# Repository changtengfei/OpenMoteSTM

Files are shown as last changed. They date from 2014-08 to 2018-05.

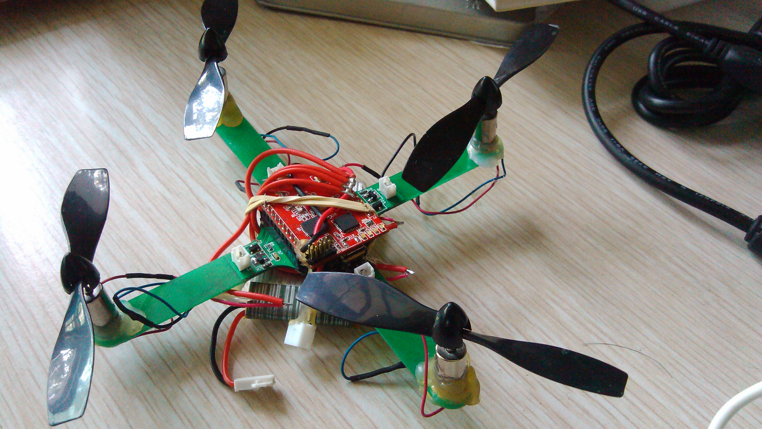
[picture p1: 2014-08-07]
openquadcopter.jpg

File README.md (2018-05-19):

View this project on [CADLAB.io](https://cadlab.io/project/1063). 

OpenSource Hardware of OpenMoteSTM
====================================================

Hello, here is the source of OpenMoteSTM board, including device library, schematic and PCB. All of those are designed by eagle. We also provide a 3d model for openmotestm using sketchUp!!! You can open the openmotestm.skp file with sketchUp to see what openmotestm looks like. Part of package/device/model came from the library of eagle and sparkfun. 

Using OpenMoteSTM with OpenWSN
====================================================

Hardware & Tools
----------------------------------------------------

* OpenMoteSTM Motes         Please Contact: tengfei.chang@gmail.com
* Micro-B USB Cables        You can buy them online anywhere, or maybe you already have one :)
* Jlink Debugger            https://www.segger.com/jlink-debug-probes.html
* Jlink adapter             https://www.segger.com/jlink-adapters-9pin-cortexm.html

Software Installation
----------------------------------------------------

* IAR Embedded Workbench for ARM : Version 6.60     http://www.iar.com
* python 2.7:               http://python.org/download/
* PySerial 2.6:             http://pyserial.sourceforge.net/
* PyDispatcher 2.0.3:       http://pydispatcher.sourceforge.net/
* PyWin32:                  https://sourceforge.net/projects/pywin32/files/pywin32/
* SCons:                    http://scons.org/download.php
* Tap for Windows:          http://openvpn.net/index.php/download/community-downloads.html
* Silicon Labs CP2102:      http://www.silabs.com/support/pages/document-library.aspx?p=Interface&f=USB%20Bridges&pn=CP2102

Installation of Tap
----------------------------------------------------
1. install tun
2. configure tun
    * Go: "Start"->"Programs"->Tap For Windows->utilities->"Add a new TAP virtual ethernet adapter" 
    * Open Network Adapter，Looking for "Local Area Connection" adapter which is created by Tap windows
    * Rename it by "OpenWSN"
    * Enter following code in a windows command prompt， setting IP：
    
            netsh interface ipv4 add address name=OpenWSN address=10.2.0.1 mask=255.255.0.0
            netsh interface ipv6 add address interface=OpenWSN address=bbbb::1/64   
    
    * Enable Routing ("IEEE802.3" is the network interface you are using to connect to internet)

            netsh interface ipv4 set interface interface=IEEE802.3 forwarding=enabled
            netsh interface ipv4 set interface interface=OpenWSN forwarding=enabled

            netsh interface ipv6 set interface interface=IEEE802.3 forwarding=enabled
            netsh interface ipv6 set interface interface=OpenWSN forwarding=enabled
    
    * Add path to routing table

            netsh interface ipv6 delete route bbbb::/64 OpenWSN
            netsh interface ipv6 add    route bbbb::/64 OpenWSN fe80::8

Source Code
-----------------------------------------------------
* openwsn-sw:               https://codeload.github.com/openwsn-berkeley/openwsn-sw/zip/REL-1.8.0
* openwsn-fw:               https://codeload.github.com/openwsn-berkeley/openwsn-fw/zip/REL-1.8.0
* coap:                     https://codeload.github.com/openwsn-berkeley/coap/zip/develop

-All extracted folders need to be place at same level-

Downloading led_blink Program
-----------------------------------------------------
1. Open "IAR for ARM"
2. GO: File->Open->Workspace
3. choosing "openmotestm.eww"
    * the file is at : openwsn-fw-REL-1.8.0\projects\openmotestm directory
4. All the projects will shown on the Workspace(left of the GUI)，right click to select "01bsp_leds-Debug" project, then choose "Set as Active" in the prompt menu.    
5. Downloading and Debugging by left clicking the "Green Triangle Button",
    * tips: "Ctrl + D" is the short-cut of this functions
6. After downloading，IAR will stop at debugging mode. Press F5 to start the program. You will see the LEDs will blink by sequence

Using OpenWSN Program
-----------------------------------------------------
1. Downloading "03oos_openwsn-Debug" program by the procedures above
2. Connect OpenMoteSTM to PC by USB Cabel，PC will install the Silicon driver for OpenMoteSTM
3. Open a windows prompt, and enter the following code to start openvisualizer
        cd "Your\openwsn-sw_REL-1.8.0\Directory"\software\openvisualizer\
        scons runweb
3. Open your favourite brower and type in "localhost:8080" or "127.0.0.1:8080", You will see the openwsn openvisualizer page.
4. click "toggle" button to set the mote as DAGROOT. If everything goes well, you will find the blue LED light and the green one blinks. To see what's going behind them, please visit: http://openwsn.org

Contact & Help
-----------------------------------------------------
If you have any questions, please don't hesitate to contact tengfei.chang@gmail.com

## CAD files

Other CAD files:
3dmodel/USBDongle.skp
3dmodel/openmotestm-kit.skp
3dmodel/openmotestm.skp
3dmodel/openquadcopter.skp
3dmodel/testbed-plank.skp

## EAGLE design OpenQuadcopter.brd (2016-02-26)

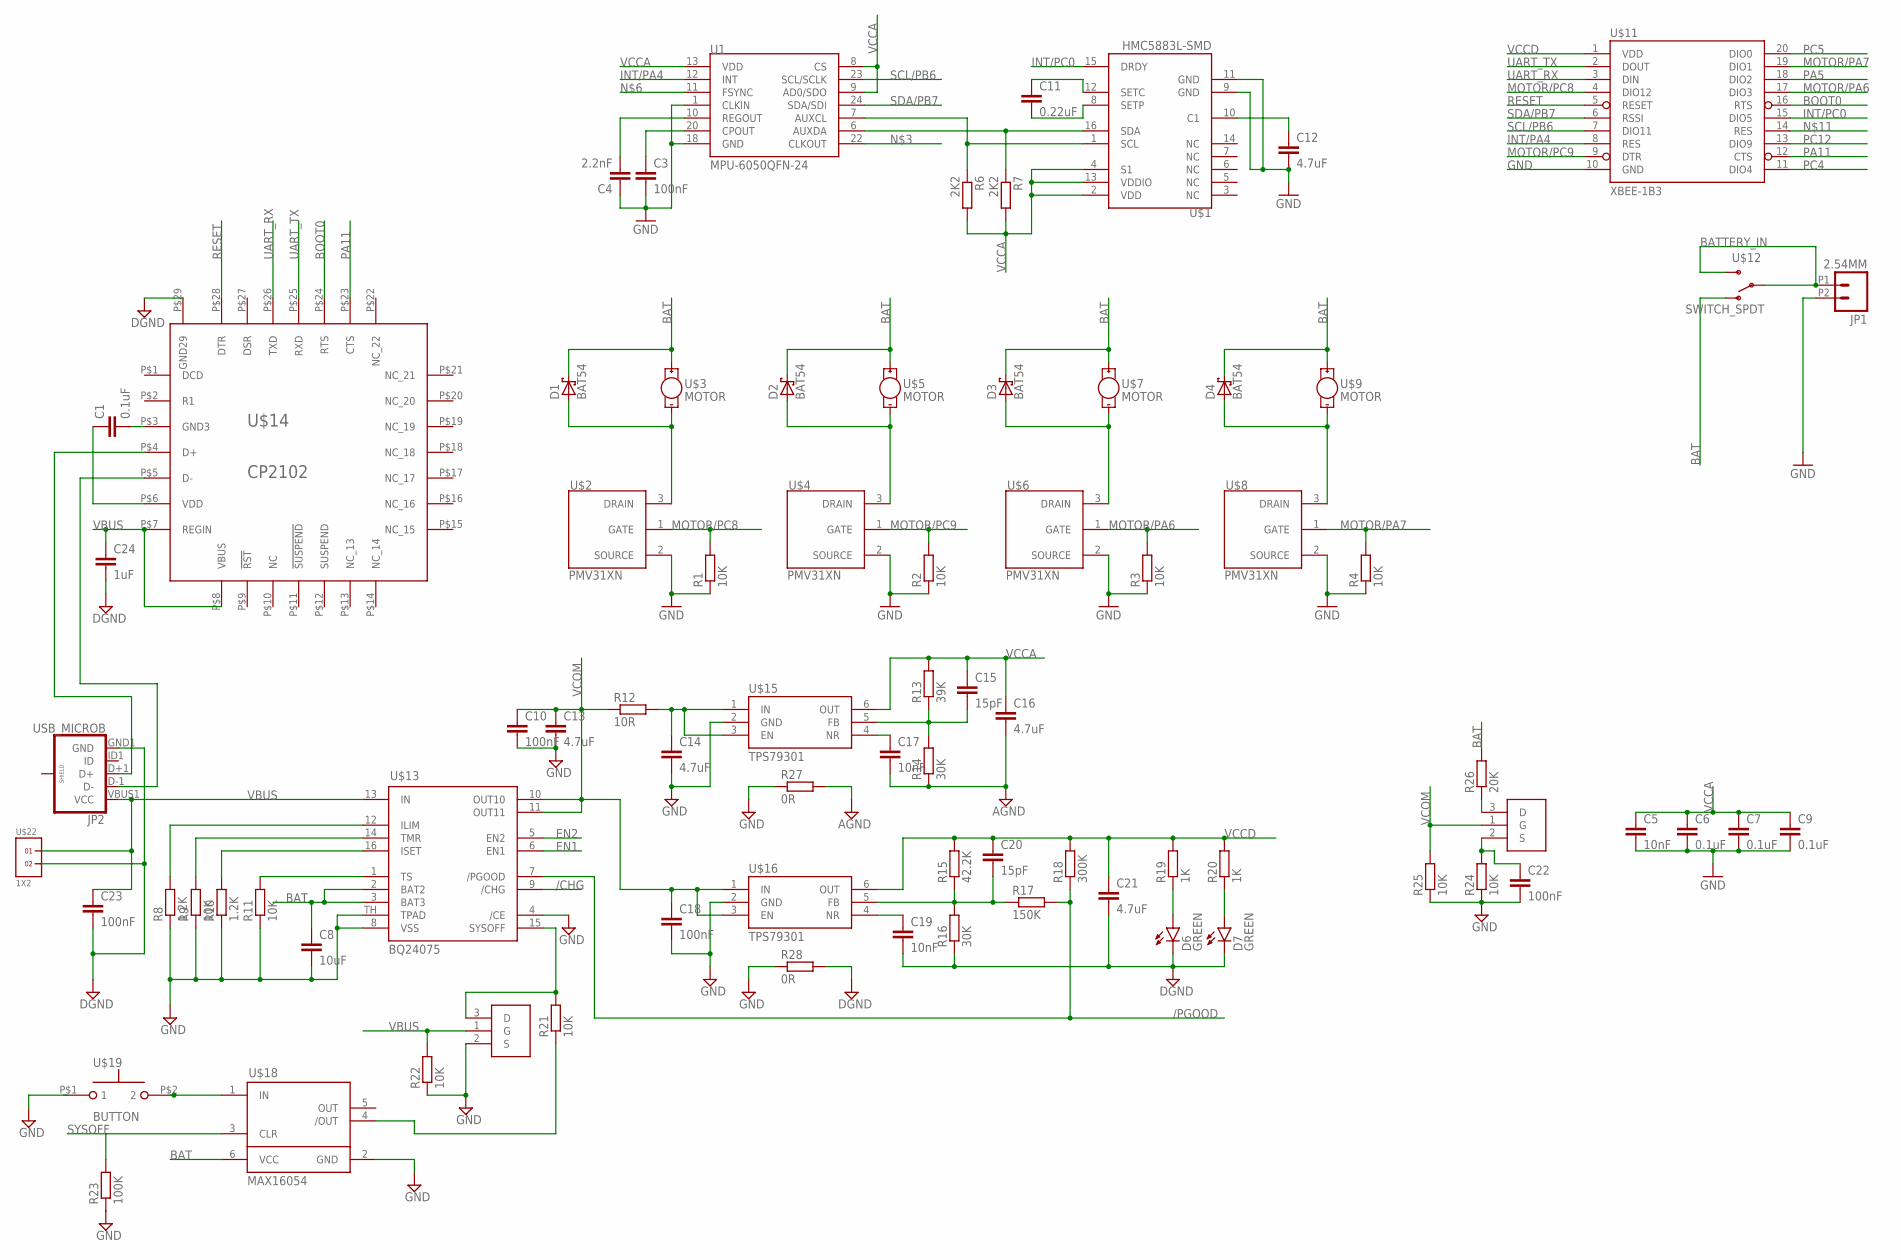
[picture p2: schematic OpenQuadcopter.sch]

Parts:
C1, C6, C7, C9: 0.1uF; C0402
C3, C10, C18, C22, C23: 100nF; C0402
C4: 2.2nF; C0402
C5, C17, C19: 10nF; C0402
C8: 10uF; C0603
C11: 0.22uF; C0402
C12, C13, C14, C16, C21: 4.7uF; C0603
C15, C20: 15pF; C0402
C24: 1uF; C0603
D1, D2, D3, D4: BAT54; SOT23
D6, D7: GREEN; LED-0603
JP1: 2.54MM; 1X02_2.54_SCREWTERM
JP2: USB_MICROB; USB-B-MICRO-SMD_V03
R1, R2, R3, R4, R9, R11, R21, R22, R24, R25: 10K; R0402
R6, R7: 2K2; R0402
R8, R10: 1.2K; R0402
R12: 10R; R0402
R13: 39K; R0402
R14, R16: 30K; R0402
R15: 42.2K; R0402
R17: 150K; R0402
R18: 300K; R0402
R19, R20: 1K; R0402
R23: 100K; R0402
R26: 20K; R0402
R27, R28: 0R; R0402
U1: MPU-6050QFN-24; QFN-24-TESTING
U$1: HMC5883L-SMD; 16LPCC
U$2, U$4, U$6, U$8: PMV31XN; SOT23-W
U$3, U$5, U$7, U$9: MOTOR; VIBE-MOTOR-10MM
U$11: XBEE-1B3; XBEE-SMD
U$12: SWITCH_SPDT; KPS-1290
U$13: BQ24075; QFN16
U$14: CP2102; QFN28-5X5
U$15, U$16: TPS79301; SOT23-6
U$17, U$20: 2N7002; SOT23-3
U$18: MAX16054; SOT23-6
U$19: BUTTON
U$22: 1X2

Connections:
/CHG: U$13.9 (/CHG)
/PGOOD: R17.2, R18.1, U$13.7 (/PGOOD)
AGND: C16.2, C17.2, R14.1, R27.2
BAT: C8.1, D1.3 (C), D2.3 (C), D3.3 (C), D4.3 (C), R26.2, U$3.+, U$5.+, U$7.+, U$9.+, U$12.O, U$13.2 (BAT2), U$13.3 (BAT3), U$18.6 (VCC)
BATTERY_IN: JP1.P1 (1), U$12.P, U$12.S
BOOT0: U$11.16 (RTS), U$14.P$24 (RTS)
DGND: C19.2, C21.2, C23.2, C24.2, D6.C, D7.C, JP2.GND1 (GND), R16.1, R28.2, U$14.P$29 (GND29), U$22.2
EN1: U$13.6 (EN1)
EN2: U$13.5 (EN2)
GND: C3.2, C4.1, C5.2, C6.2, C7.2, C8.2, C9.2, C10.2, C12.2, C13.2, C14.2, C18.2, C22.2, JP1.P2 (2), R1.1, R2.1, R3.1, R4.1, R8.1, R9.1, R10.1, R11.1, R22.1, R23.1, R24.1, R25.1, R27.1, R28.1, U1.1 (CLKIN), U1.18 (GND), U$1.9 (GND), U$1.11 (GND), U$2.2 (SOURCE), U$4.2 (SOURCE), U$6.2 (SOURCE), U$8.2 (SOURCE), U$11.10 (GND), U$13.4 (/CE), U$13.8 (VSS), U$13.TH (TPAD), U$15.2 (GND), U$16.2 (GND), U$17.2 (S), U$18.2 (GND)
INT/PA4: U1.12 (INT), U$11.8 (RES)
INT/PC0: U$1.15 (DRDY), U$11.15 (DIO5)
MOTOR/PA6: R3.2, U$6.1 (GATE), U$11.17 (DIO3)
MOTOR/PA7: R4.2, U$8.1 (GATE), U$11.19 (DIO1)
MOTOR/PC8: R1.2, U$2.1 (GATE), U$11.4 (DIO12)
MOTOR/PC9: R2.2, U$4.1 (GATE), U$11.9 (DTR)
unnamed: D2.1 (A), U$4.3 (DRAIN), U$5.-
unnamed: D1.1 (A), U$2.3 (DRAIN), U$3.-
unnamed: R6.1, U1.7 (AUXCL), U$1.1 (SCL)
unnamed: D3.1 (A), U$6.3 (DRAIN), U$7.-
unnamed: D4.1 (A), U$8.3 (DRAIN), U$9.-
unnamed: R7.1, U1.6 (AUXDA), U$1.16 (SDA)
unnamed: C4.2, U1.10 (REGOUT)
unnamed: C1.2, U$14.P$3 (GND3)
unnamed: C3.1, U1.20 (CPOUT)
unnamed: C11.1, U$1.12 (SETC)
unnamed: C11.2, U$1.8 (SETP)
unnamed: R21.1, U$18.4 (/OUT)
unnamed: C12.1, U$1.10 (C1)
unnamed: C1.1, U$14.P$6 (VDD)
unnamed: R8.2, U$13.12 (ILIM)
unnamed: R9.2, U$13.14 (TMR)
unnamed: R10.2, U$13.16 (ISET)
unnamed: R11.2, U$13.1 (TS)
unnamed: R21.2, U$13.15 (SYSOFF), U$17.3 (D)
unnamed: C14.1, R12.2, U$15.1 (IN), U$15.3 (EN)
unnamed: U$18.1 (IN), U$19.P$2 (2)
unnamed: C15.2, R13.1, R14.2, U$15.5 (FB)
unnamed: C17.1, U$15.4 (NR)
unnamed: C19.1, U$16.4 (NR)
unnamed: C20.2, R15.1, R16.2, R17.1, U$16.5 (FB)
unnamed: C22.1, R24.2, U$20.2 (S)
unnamed: D6.A, R19.1
unnamed: D7.A, R20.1
unnamed: R26.1, U$20.3 (D)
unnamed: JP2.D+1 (D+), U$14.P$4 (D+)
unnamed: JP2.D-1 (D-), U$14.P$5 (D-)
PA5: U$11.18 (DIO2)
PA11: U$11.12 (CTS), U$14.P$23 (CTS)
PC4: U$11.11 (DIO4)
PC5: U$11.20 (DIO0)
PC12: U$11.13 (DIO9)
RESET: U$11.5 (RESET), U$14.P$28 (DTR)
SCL/PB6: U1.23 (SCL/SCLK), U$11.7 (DIO11)
SDA/PB7: U1.24 (SDA/SDI), U$11.6 (RSSI)
SYSOFF: R23.2, U$18.3 (CLR)
UART_RX: U$11.3 (DIN), U$14.P$26 (TXD)
UART_TX: U$11.2 (DOUT), U$14.P$25 (RXD)
VBUS: C23.1, C24.1, JP2.VBUS1 (VCC), R22.2, U$13.13 (IN), U$14.P$7 (REGIN), U$14.P$8 (VBUS), U$17.1 (G), U$22.1
VCCA: C5.1, C6.1, C7.1, C9.1, C15.1, C16.1, R6.2, R7.2, R13.2, U1.8 (CS), U1.9 (AD0/SDO), U1.13 (VDD), U$1.2 (VDD), U$1.4 (S1), U$1.13 (VDDIO), U$15.6 (OUT)
VCCD: C20.1, C21.1, R15.2, R18.2, R19.2, R20.2, U$11.1 (VDD), U$16.6 (OUT)
VCOM: C10.1, C13.1, C18.1, R12.1, R25.2, U$13.10 (OUT10), U$13.11 (OUT11), U$16.1 (IN), U$16.3 (EN), U$20.1 (G)

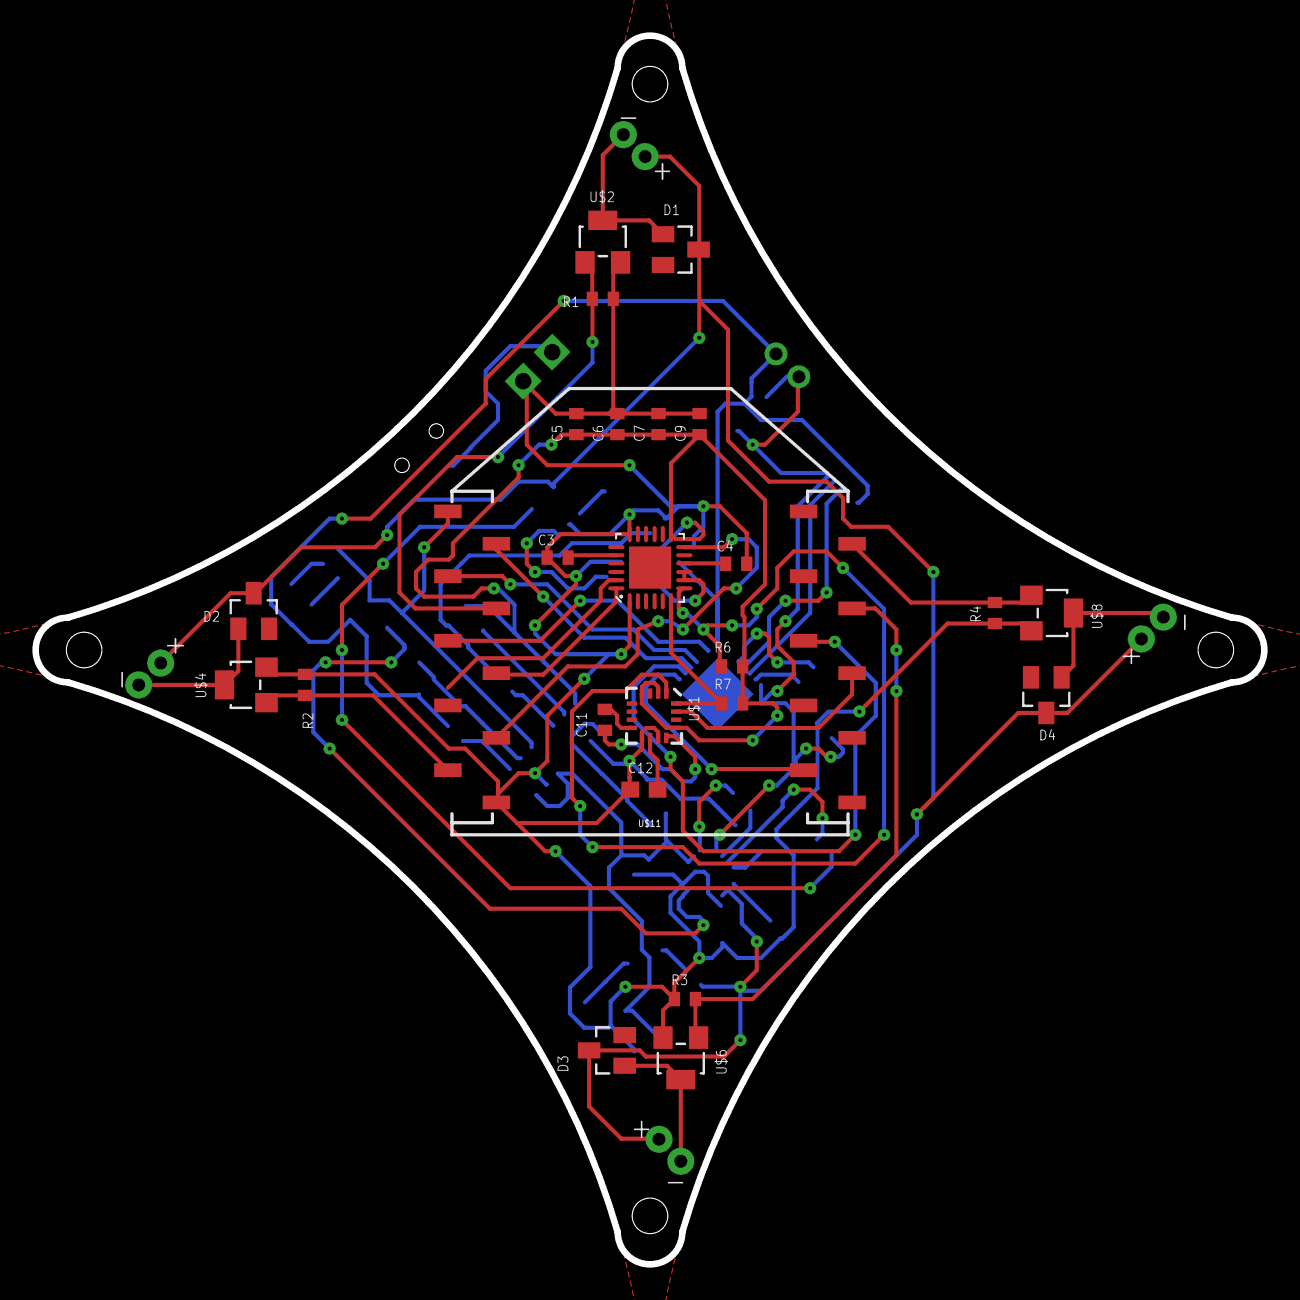
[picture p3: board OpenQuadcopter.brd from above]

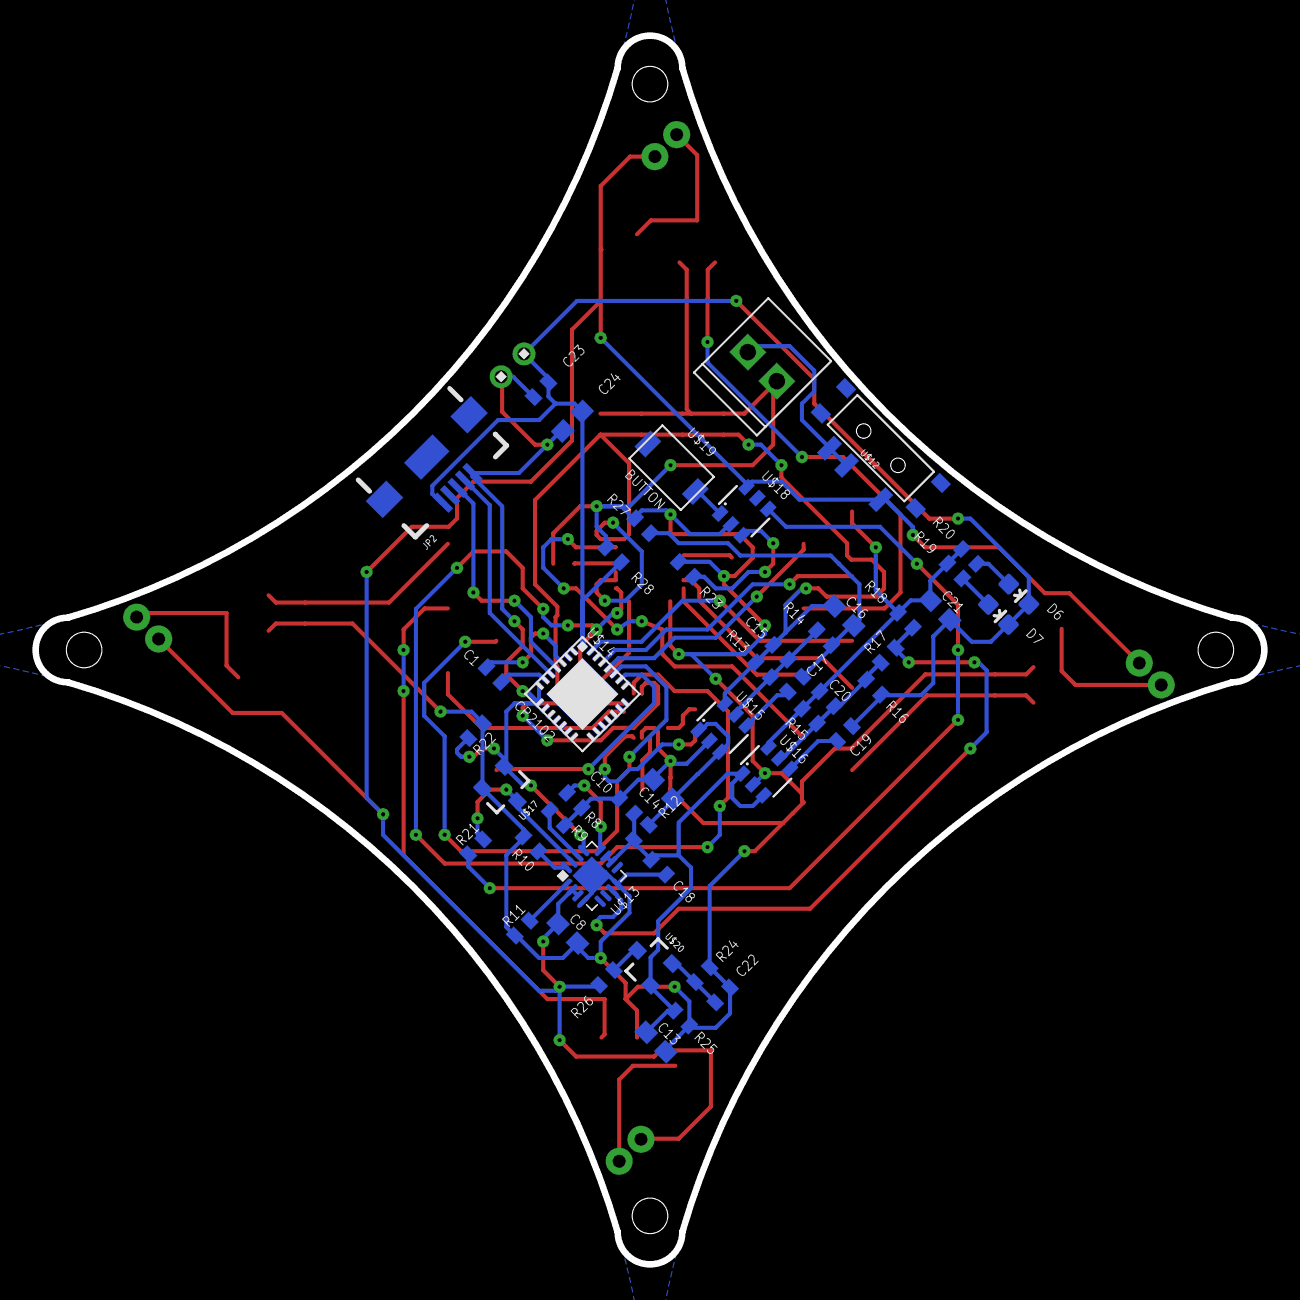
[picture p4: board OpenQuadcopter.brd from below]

Board: 2 copper layers, 76.0 x 76.0 mm, 79 parts (50 on the bottom side), 55 nets.

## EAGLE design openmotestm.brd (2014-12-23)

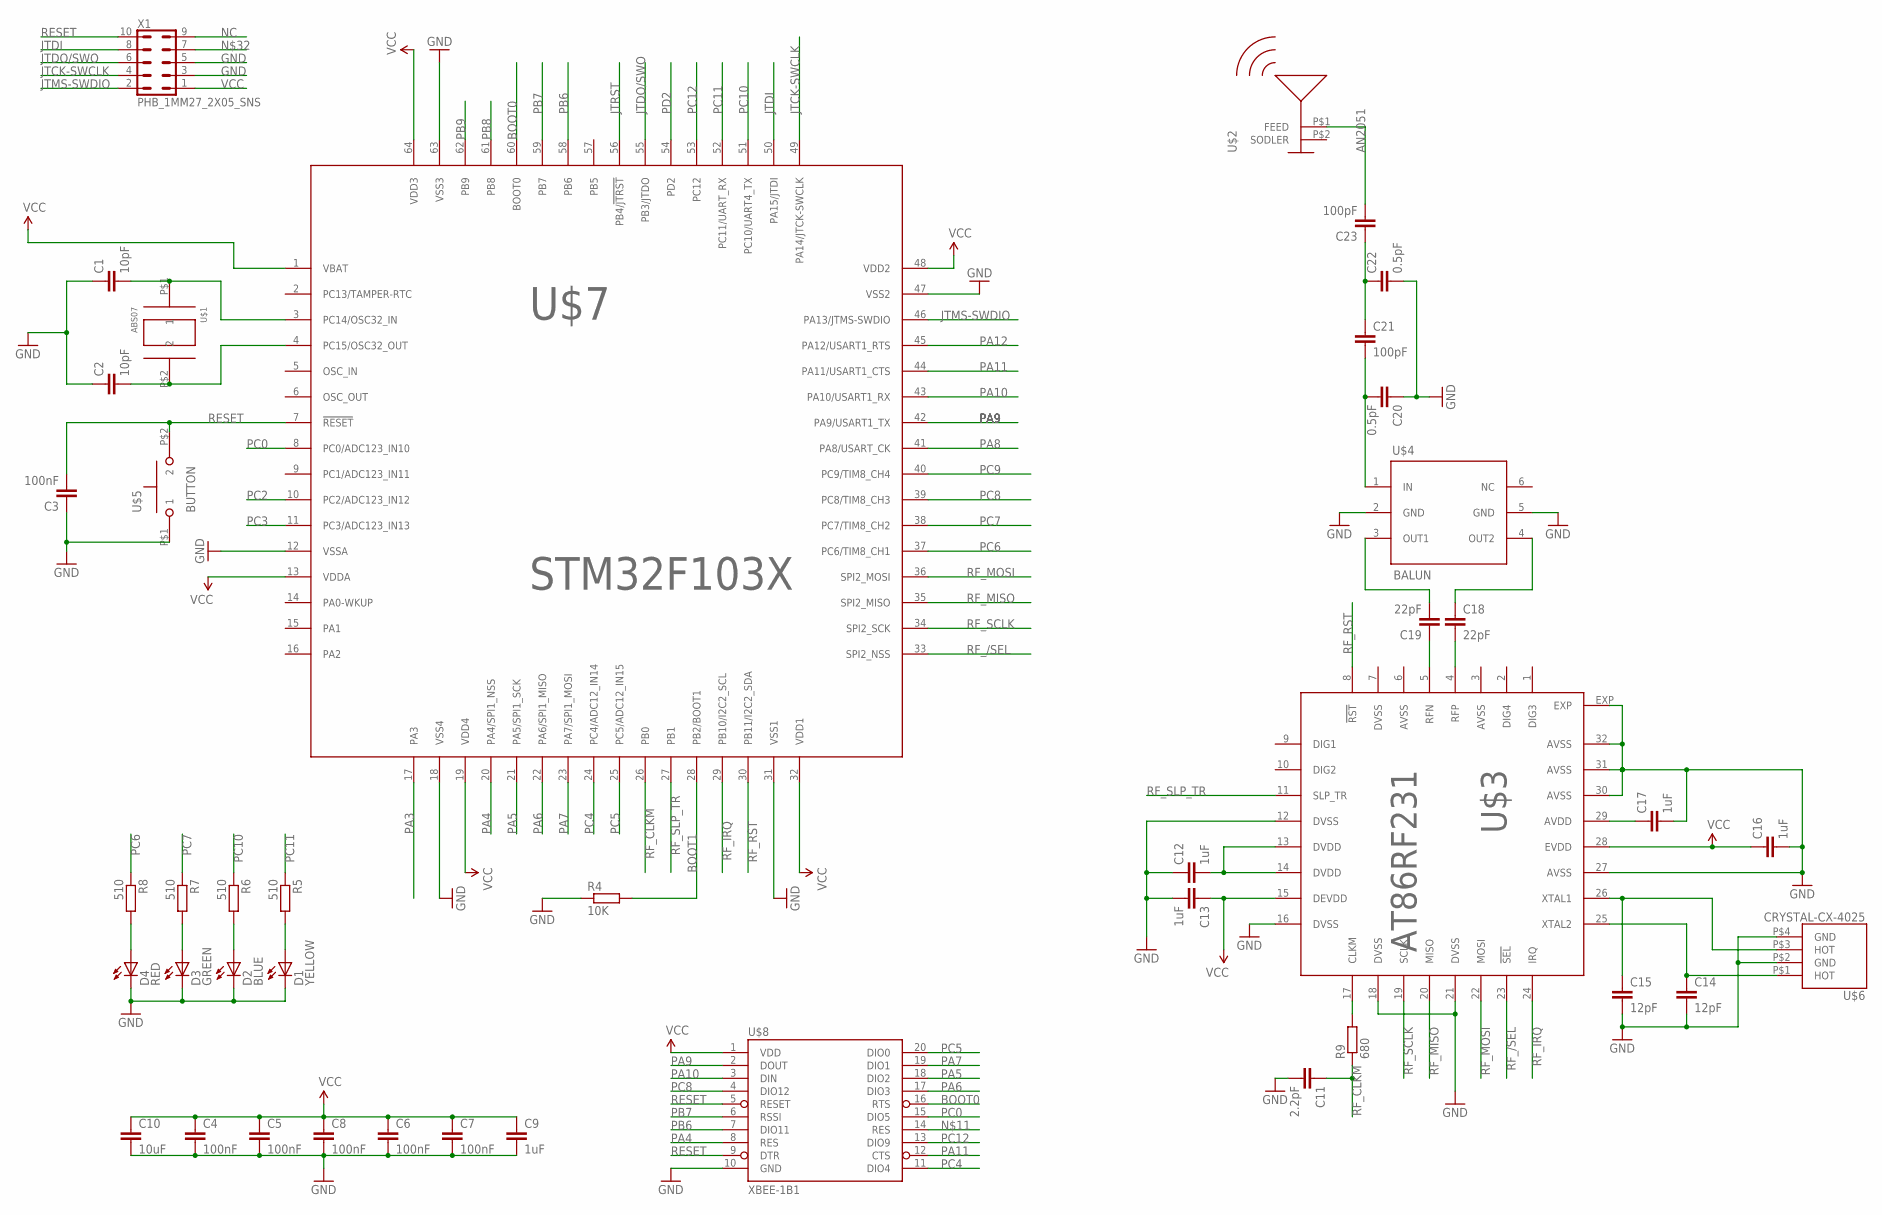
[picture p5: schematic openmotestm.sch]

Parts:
C1, C2: 10pF; C0402
C3, C4, C5, C6, C7, C8: 100nF; C0402
C9, C12, C13, C16, C17: 1uF; C0603
C10: 10uF; C0603
C11: 2.2pF; C0402
C14, C15: 12pF; C0402
C18, C19: 22pF; C0402
C20, C22: 0.5pF; C0402
C21, C23: 100pF; C0402
D1: YELLOW; LED-0603
D2: BLUE; LED-0603
D3: GREEN; LED-0603
D4: RED; LED-0603
R4: 10K; R0402
R5, R6, R7, R8: 510; R0402
R9: 680; R0402
U$1: ABS07
U$2: AN2051
U$3: AT86RF231; QFN32
U$4: BALUN
U$5: BUTTON
U$6: CRYSTAL-CX-4025; CX-4025
U$7: STM32F103X; LQFP-ST-64-2
U$8: XBEE-1B1; XBEE-1
X1: PHB_1MM27_2X05_SNS

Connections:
BOOT0: U$7.60 (BOOT0), U$8.16 (RTS)
BOOT1: R4.2, U$7.28 (PB2/BOOT1)
GND: C1.1, C2.1, C3.1, C4.2, C5.2, C6.2, C7.2, C8.2, C9.2, C10.2, C11.2, C12.1, C13.2, C14.2, C15.2, C16.2, C17.2, C20.1, C22.2, D1.C, D2.C, D3.C, D4.C, R4.1, U$3.12 (DVSS), U$3.16 (DVSS), U$3.18 (DVSS), U$3.21 (DVSS), U$3.27 (AVSS), U$3.30 (AVSS), U$3.31 (AVSS), U$3.32 (AVSS), U$3.EXP, U$4.2 (GND), U$4.5 (GND), U$5.P$1 (1), U$6.P$2 (GND), U$6.P$4 (GND), U$7.12 (VSSA), U$7.18 (VSS4), U$7.31 (VSS1), U$7.47 (VSS2), U$7.63 (VSS3), U$8.10 (GND), X1.3, X1.5
JTCK-SWCLK: U$7.49 (PA14/JTCK-SWCLK), X1.4
JTDI: U$7.50 (PA15/JTDI), X1.8
JTDO/SWO: U$7.55 (PB3/JTDO), X1.6
JTMS-SWDIO: U$7.46 (PA13/JTMS-SWDIO), X1.2
JTRST: U$7.56 (PB4/!JTRST)
unnamed: C1.2, U$1.P$1 (1), U$7.3 (PC14/OSC32_IN)
unnamed: C2.2, U$1.P$2 (2), U$7.4 (PC15/OSC32_OUT)
unnamed: R9.2, U$3.17 (CLKM)
unnamed: C14.1, U$3.25 (XTAL2), U$6.P$1 (HOT)
unnamed: D1.A, R5.2
unnamed: D2.A, R6.2
unnamed: D3.A, R7.2
unnamed: D4.A, R8.2
unnamed: C15.1, U$3.26 (XTAL1), U$6.P$3 (HOT)
unnamed: C12.2, U$3.13 (DVDD), U$3.14 (DVDD)
unnamed: C18.2, U$3.4 (RFP)
unnamed: C19.1, U$3.5 (RFN)
unnamed: C19.2, U$4.3 (OUT1)
unnamed: C17.1, U$3.29 (AVDD)
unnamed: C18.1, U$4.4 (OUT2)
unnamed: C20.2, C21.2, U$4.1 (IN)
unnamed: C21.1, C22.1, C23.1
unnamed: C23.2, U$2.P$1 (FEED)
NC: X1.9
PA3: U$7.17 (PA3)
PA4: U$7.20 (PA4/SPI1_NSS), U$8.8 (RES)
PA5: U$7.21 (PA5/SPI1_SCK), U$8.18 (DIO2)
PA6: U$7.22 (PA6/SPI1_MISO), U$8.17 (DIO3)
PA7: U$7.23 (PA7/SPI1_MOSI), U$8.19 (DIO1)
PA8: U$7.41 (PA8/USART_CK)
PA9: U$7.42 (PA9/USART1_TX), U$8.2 (DOUT)
PA10: U$7.43 (PA10/USART1_RX), U$8.3 (DIN)
PA11: U$7.44 (PA11/USART1_CTS), U$8.12 (CTS)
PA12: U$7.45 (PA12/USART1_RTS)
PB6: U$7.58 (PB6), U$8.7 (DIO11)
PB7: U$7.59 (PB7), U$8.6 (RSSI)
PB8: U$7.61 (PB8)
PB9: U$7.62 (PB9)
PC0: U$7.8 (PC0/ADC123_IN10), U$8.15 (DIO5)
PC2: U$7.10 (PC2/ADC123_IN12)
PC3: U$7.11 (PC3/ADC123_IN13)
PC4: U$7.24 (PC4/ADC12_IN14), U$8.11 (DIO4)
PC5: U$7.25 (PC5/ADC12_IN15), U$8.20 (DIO0)
PC6: R8.1, U$7.37 (PC6/TIM8_CH1)
PC7: R7.1, U$7.38 (PC7/TIM8_CH2)
PC8: U$7.39 (PC8/TIM8_CH3), U$8.4 (DIO12)
PC9: U$7.40 (PC9/TIM8_CH4)
PC10: R6.1, U$7.51 (PC10/UART4_TX)
PC11: R5.1, U$7.52 (PC11/UART_RX)
PC12: U$7.53 (PC12), U$8.13 (DIO9)
PD2: U$7.54 (PD2)
RESET: C3.2, U$5.P$2 (2), U$7.7 (!RESET), U$8.5 (RESET), U$8.9 (DTR), X1.10
RF_/SEL: U$3.23 (!SEL), U$7.33 (SPI2_NSS)
RF_CLKM: C11.1, R9.1, U$7.26 (PB0)
RF_IRQ: U$3.24 (IRQ), U$7.29 (PB10/I2C2_SCL)
RF_MISO: U$3.20 (MISO), U$7.35 (SPI2_MISO)
RF_MOSI: U$3.22 (MOSI), U$7.36 (SPI2_MOSI)
RF_RST: U$3.8 (!RST), U$7.30 (PB11/I2C2_SDA)
RF_SCLK: U$3.19 (SCLK), U$7.34 (SPI2_SCK)
RF_SLP_TR: U$3.11 (SLP_TR), U$7.27 (PB1)
VCC: C4.1, C5.1, C6.1, C7.1, C8.1, C9.1, C10.1, C13.1, C16.1, U$3.15 (DEVDD), U$3.28 (EVDD), U$7.1 (VBAT), U$7.13 (VDDA), U$7.19 (VDD4), U$7.32 (VDD1), U$7.48 (VDD2), U$7.64 (VDD3), U$8.1 (VDD), X1.1

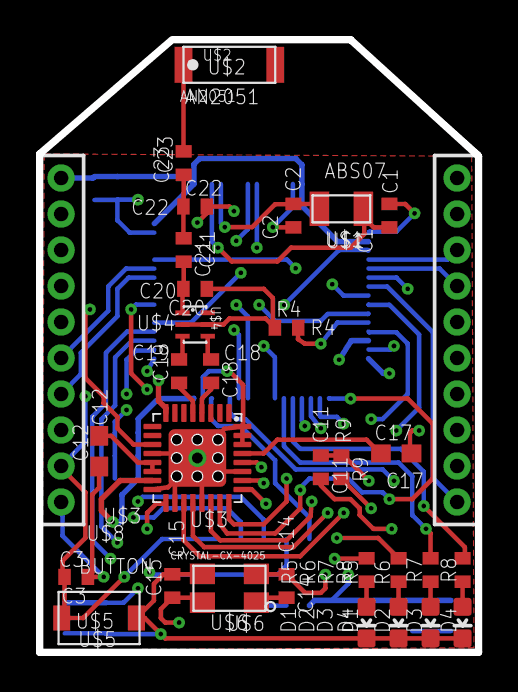
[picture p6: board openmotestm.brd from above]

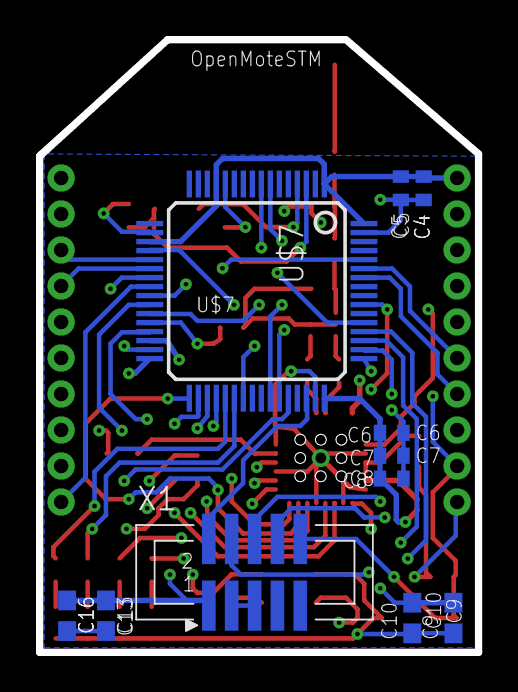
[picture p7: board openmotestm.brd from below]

Board: 4 copper layers, 24.4 x 34.0 mm, 42 parts (11 on the bottom side), 53 nets.

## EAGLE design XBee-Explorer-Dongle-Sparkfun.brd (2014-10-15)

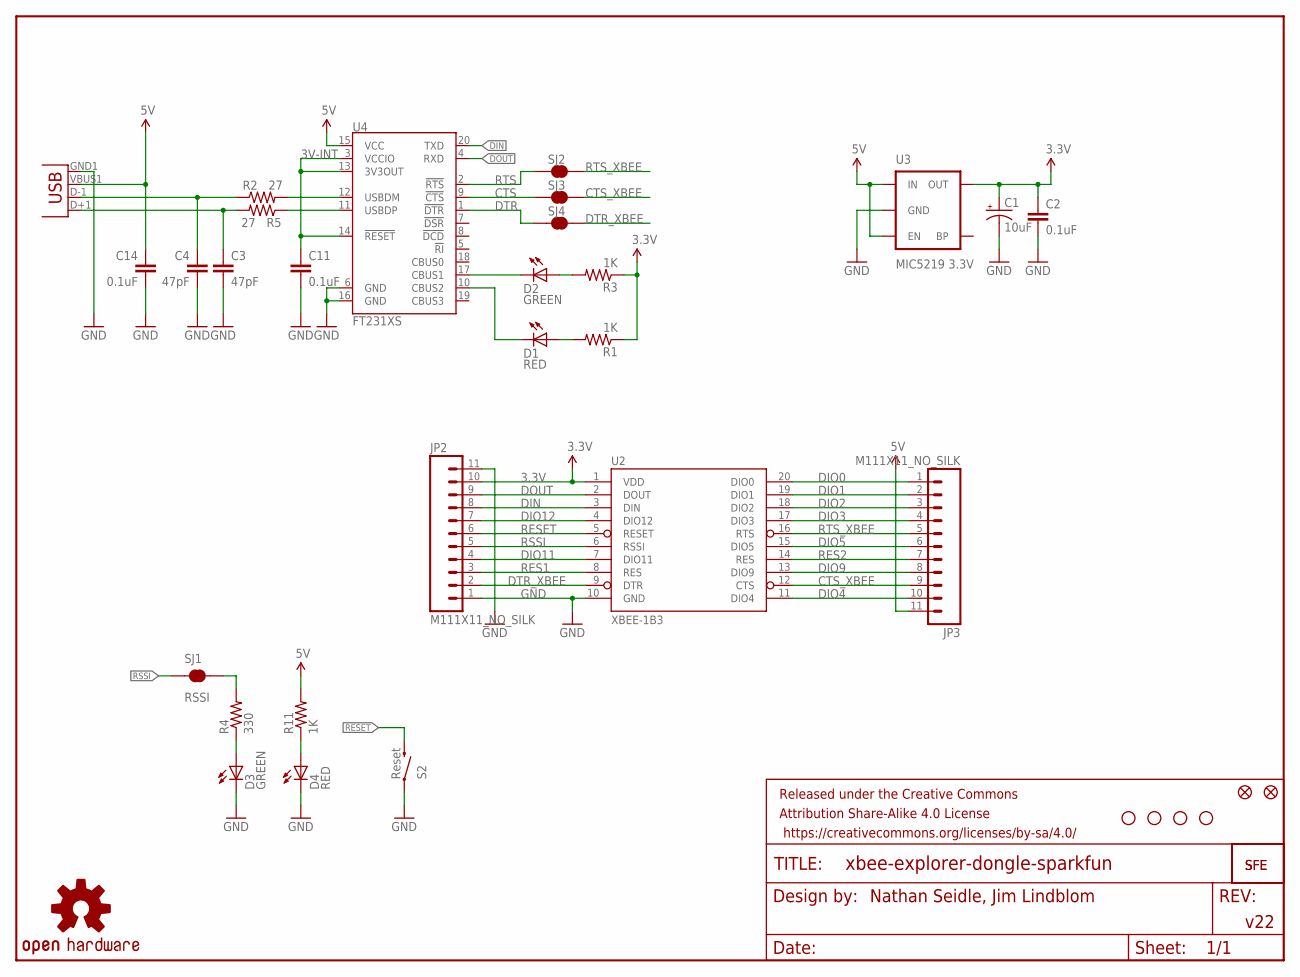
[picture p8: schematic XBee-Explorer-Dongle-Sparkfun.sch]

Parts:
C1: 10uF; EIA3216
C2, C11, C14: 0.1uF; 0603-CAP
C3, C4: 47pF; 0603-CAP
D1, D4: RED; LED-0603
D2, D3: GREEN; LED-0603
FID1, FID2: FIDUCIAL1X2; FIDUCIAL-1X2
FRAME1: FRAME-LETTER; CREATIVE_COMMONS
JP1: USBA-SMD-MALE-LOCKING; USB-A-SMT-MALE-LOCKING
JP2, JP3: M111X11_NO_SILK; 1X11_NO_SILK
R1, R3, R11: 1K; 0603-RES
R2, R5: 27; 0603-RES
R4: 330; 0603-RES
S2: Reset; TACTILE_SWITCH_SMD
SJ1, SJ2, SJ3, SJ4: RSSI; SJ_2S-TRACE
U2: XBEE-1B3; XBEE-SMD
U3: MIC5219 3.3V; SOT23-5
U4: FT231XS; SSOP20_L
U$1: LOGO-SFESK; SFE-LOGO-FLAME
U$4: LOGO-SFENEW; SFE-NEW-WEBLOGO
U$5, U$9, U$10, U$11: STAND-OFF
U$7: OSHW-LOGOS; OSHW-LOGO-S

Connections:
3.3V: C1.A (+), C2.1, JP2.10, R1.1, R3.1, U2.1 (VDD), U3.5 (OUT)
3V-INT: C11.1, U4.3 (VCCIO), U4.13 (3V3OUT), U4.14 (!RESET)
5V: C14.1, JP1.VBUS1 (VBUS), JP3.11, R11.2, U3.1 (IN), U3.3 (EN), U4.15 (VCC)
CTS: SJ3.1, U4.9 (!CTS)
CTS_XBEE: JP3.9, SJ3.2, U2.12 (CTS)
DIN: JP2.8, U2.3 (DIN), U4.20 (TXD)
DIO0: JP3.1, U2.20 (DIO0)
DIO1: JP3.2, U2.19 (DIO1)
DIO2: JP3.3, U2.18 (DIO2)
DIO3: JP3.4, U2.17 (DIO3)
DIO4: JP3.10, U2.11 (DIO4)
DIO5: JP3.6, U2.15 (DIO5)
DIO9: JP3.8, U2.13 (DIO9)
DIO11: JP2.4, U2.7 (DIO11)
DIO12: JP2.7, U2.4 (DIO12)
DOUT: JP2.9, U2.2 (DOUT), U4.4 (RXD)
DTR: SJ4.1, U4.1 (!DTR)
DTR_XBEE: JP2.2, SJ4.2, U2.9 (DTR)
GND: C1.C (-), C2.2, C3.2, C4.2, C11.2, C14.2, D3.C, D4.C, JP1.GND1 (GND), JP2.1, JP2.11, S2.1, U2.10 (GND), U3.2 (GND), U4.6 (GND), U4.16 (GND)
unnamed: D1.A, R1.2
unnamed: D3.A, R4.1
unnamed: C4.1, JP1.D-1 (D-), R2.1
unnamed: D2.A, R3.2
unnamed: R2.2, U4.12 (USBDM)
unnamed: C3.1, JP1.D+1 (D+), R5.2
unnamed: R5.1, U4.11 (USBDP)
unnamed: R4.2, SJ1.2
unnamed: D4.A, R11.1
RES1: JP2.3, U2.8 (RES)
RES2: JP3.7, U2.14 (RES)
RESET: JP2.6, S2.3 (2), U2.5 (RESET)
RSSI: JP2.5, SJ1.1, U2.6 (RSSI)
RTS: SJ2.1, U4.2 (!RTS)
RTS_XBEE: JP3.5, SJ2.2, U2.16 (RTS)
RXLED: D2.C, U4.17 (CBUS1)
TXLED: D1.C, U4.10 (CBUS2)

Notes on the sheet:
Nathan Seidle, Jim Lindblom
v22

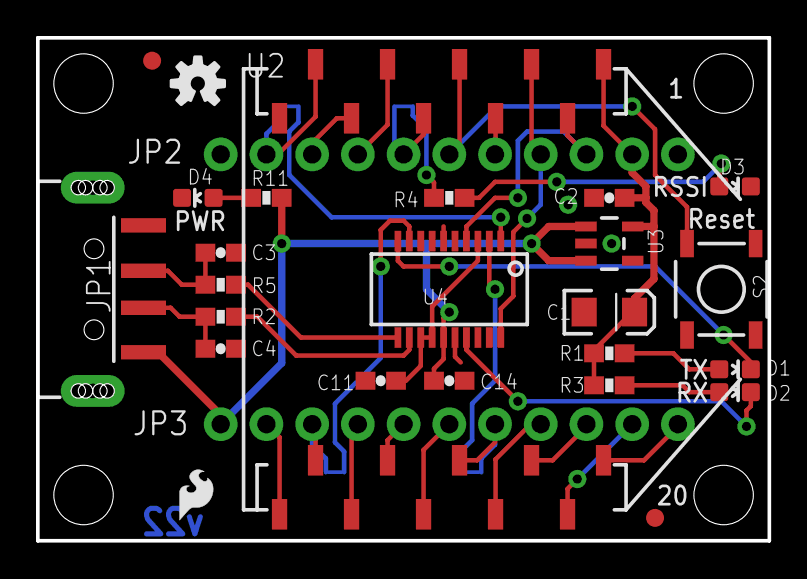
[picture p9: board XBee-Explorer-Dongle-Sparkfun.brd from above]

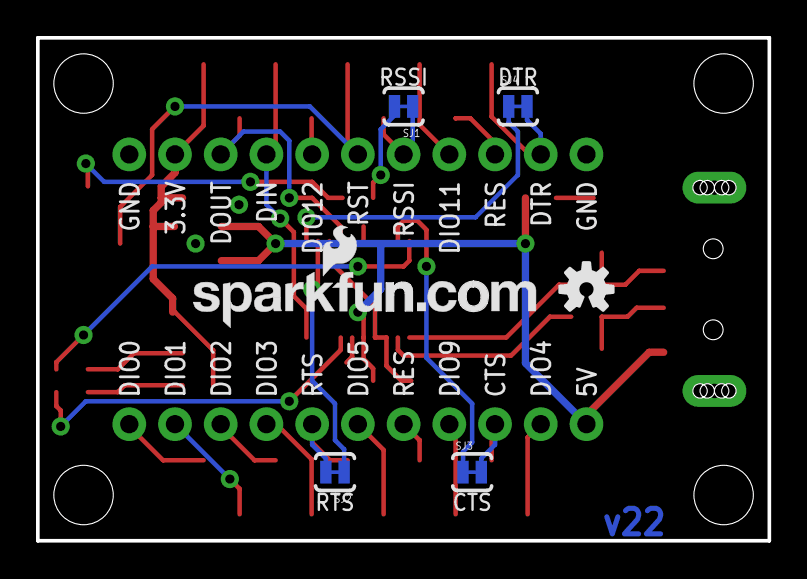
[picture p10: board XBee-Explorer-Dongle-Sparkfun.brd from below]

Board: 2 copper layers, 40.6 x 27.9 mm, 38 parts (6 on the bottom side), 36 nets.

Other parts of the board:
U$8: OSHW-LOGOS; OSHW-LOGO-S

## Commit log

2014-07-28 Update library and schematic.
    [openmotestm.sch]
2014-07-29 add sch and brd
    [openmotestm.brd, openmotestm.sch]
2014-07-29 finish the board
    [openmotestm.brd]
2014-07-31 right position in brd.
    [openmotestm.brd]
2014-07-31 add skp 3d model file for openmotestm.
    [openmotestm.skp]
2014-08-04 update sketchup model
    [openmotestm.skp]
2014-08-07 change the footprint of capacity larger than 1uF to 0603 footprint. Update 3D sketchUp model
    [openmotestm.brd, openmotestm.sch, openmotestm.skp]
2014-08-08 add xbee battery board, openquadcopter's schematic and pcb file.
    [OpenQuadcopter.brd, OpenQuadcopter.sch, Xbee Battery.brd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]
2014-08-09 wrap up openquadcopter board.
    [OpenQuadcopter.brd, OpenQuadcopter.sch]
2014-08-11 Change the PWM's TIM. (Do not use TIM1 for pwm, since the pins are also related to SPI pins)
    [OpenQuadcopter.brd, OpenQuadcopter.sch]
2014-08-11 Add holes as a pendant.
    [OpenQuadcopter.brd]
2014-08-12 update openquadcopter.
    [OpenQuadcopter.brd, OpenQuadcopter.sch]
2014-08-15 change the pcb to satisfy minimum clearance of 5 mil
    [openmotestm.brd, openmotestm.sch]
2014-08-15 add some stuff.
    [Xbee Battery.brd, openDebugger.sch, openquadcopter.skp]
2014-08-16 update openmotestm
    [OpenQuadcopter.brd, OpenQuadcopter.sch, openmotestm.brd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]
2014-08-17 drawing quadcopter
    [OpenQuadcopter.brd, OpenQuadcopter.sch, openmotestm.brd]
2014-08-18 Amazing testbed - "The shelf", had been added.
    [USBDongle.skp, openmotestm-kit.skp, openmotestm.skp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]
2014-09-09 redesign the plank.
    [testbed-plank.skp]
2014-10-15 Add XBee-Explorer-Dongle-Sparkfun. Update openmotestm. arrange the layout of openquadcopter board.
    [OpenQuadcopter.brd, OpenQuadcopter.sch, XBee-Explorer-Dongle-Sparkfun.brd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]
2014-10-16 smooth the corner of quadcopter.
    [OpenQuadcopter.brd]
2014-10-17 add Gerber files.
    [openmotestm.GBL, openmotestm.GBO, openmotestm.GBS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]
2014-10-20 add bom file.
2014-10-23 remove unused route
    [openmotestm.brd]
2014-10-27 exchange the top layer and bottom layer.
    [openmotestm.brd]
2014-10-28 recover BOM.
2014-11-28 Fix the package of chips.
    [openmotestm.brd, openmotestm.sch]
2014-12-02 Revert "Fix the package of crystal-CX4025"
    This reverts commit 4aa64b79fca5c8ea969664931983d918d7a77836.
    [openmotestm.brd, openmotestm.sch]
2014-12-03 remove taps.
    [openmotestm.brd, openmotestm.sch]
2014-12-03 Fix place Layer.
    [openmotestm.brd]
2014-12-03 update gerber files
    [openmotestm.GBL, openmotestm.GBO, openmotestm.GBS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]
2014-12-19 Publish openquadcopter extention board.
    [OpenQuadcopter.brd, OpenQuadcopter.sch]
2014-12-23 update QFN packet to sch and brd files.
    [OpenQuadcopter.brd, openmotestm.brd, openmotestm.sch]
2015-04-06 update PB6
    [OpenQuadcopter.brd, OpenQuadcopter.sch]
2015-09-11 Correct the name PMV31XN.
    [OpenQuadcopter.brd, OpenQuadcopter.sch]
2016-02-26 add 0.1uF capacitor between VDD and GND pin of CP2102.
    [OpenQuadcopter.brd, OpenQuadcopter.sch]

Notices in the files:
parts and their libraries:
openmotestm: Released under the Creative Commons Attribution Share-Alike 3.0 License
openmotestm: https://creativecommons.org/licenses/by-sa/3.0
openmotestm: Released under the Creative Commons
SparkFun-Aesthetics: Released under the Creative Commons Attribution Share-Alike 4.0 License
